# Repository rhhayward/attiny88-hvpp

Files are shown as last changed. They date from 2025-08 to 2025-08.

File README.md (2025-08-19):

### Important

The code has been tested on a breadboard, and the original pcb has been
validated to work.  There were two changes made since ordering: 1. The
attiny88 footprint was not wide enough, so it was widened in REV002.
2. The 12v source had left and right reversed - that is fixed in REV003.

Caveat emptor:  If you order PCBs from this, be prepared for them not
to work.  You have been warned.

### ATTINY88 High Voltage Parallel Programmer

This project came from a bricked attiny88. I was changing the fuses, and after
one particular update, none of the methods to program or update fuses worked.
The programmer was unable even to read the signature or fuses. However, the code
was still working, albeit terribly slowly. An LED which previously blinked once
per second was taking minutes to complete a blink cycle. While ATTINY88
microcontrollers are inexpensive and could easily be replaced, I took it as a
challenge to unbrick this one. Reading the datasheet and online, a high voltage
parallel programmer was what was needed, but I couldn't find code or a
schematic, so I worked to get a hvpp programmer working.

This was validated working with a purple pi (off-brand rp2040), a 12v boost
regulator, and the aforementioned bricked ATTINY88. I was then able to use the
`WRITEFUS` command to unbrick the device.  I implemented a few additional
commands as well.  The entire suite of possible commands is not yet available,
but should be doable leveraging the primitives that are already implemented.

### How to

The wiring is laid out in the .ino file. The only additional circuitry is that
the 5v providing the ATTINY88's VCC and the 12v necessary for the RST pin are
switched using a transistor+mosfet. All other wiring is direct from the purple
pi to the ATTINY88.  You can see the full schematic in
`/kicad/attiny88-hvpp.kicad_sch`
(https://kicanvas.org/?github=https%3A%2F%2Fgithub.com%2Frhhayward%2Fattiny88-hvpp%2Ftree%2Fmain%2Fkicad).

Once wired, you canbuild and push the code to the purple pi. I have tested this
using the Arduino IDE 2 with the Raspberry Pi Pico profile which worked for me
with no trouble. With the code running, connect to the purple pi's USB Serial
port.  The code will always prefix its output with a `*`.  It will emit some
help on start.  Once it announces done, you can start issuing commands.

## Commands

* `READSIG` - read and display signature bytes
* `READCAL` - read and display calibration byte
* `READFUS` - read and display fuse and lock bytes
* `READFLA 0x<START> 0x<END>` - read and display flash from start to end
* `WRITEFUS 0x<low> 0x<high> 0x<extended>` - write low high and extended
  fuses, then read and display fuse and lock bytes

## Example execution

```
* starting up
* setting up pin modes and values
* setting up pin modes and values - DONE
* entering programming mode
* entering programming mode - DONE
* Commands:
* READSIG - read signature and write to stdout
* READCAL - read calibration byte and write to stdout
* READFUS - read fuses and lock bytes
* READFLA 0x<START> 0x<END> - read flash from START to END.  Each must be 4 hex digits.
* WRITEFUS 0x<LOW> 0x<HIGH> 0x<EXTENDED> - write LOW HIGH and EXTENDED fuses.  Each must be 2 hex digits.
* * * ready
```
```
READSIG
```
```
* SIGNATURE: 0x1E,0x93,0x11 IDENT: ATTINY88
```
```
READFUS
```
```
* FUSE l=0x37 h=0xDF x=0xFF LOCK 0xFF
```
```
READCAL
```
```
* calibration byte: 0x9D
```
```
READFLA 0x0000 0x0010
```
```
* start=0x0000 end=0x0010
* 0x0000   13c0 22c0 21c0 20c0 1fc0 1ec0 1dc0 1cc0  1bc0 1ac0 19c0 18c0 17c0 16c0 74c0 14c0
```

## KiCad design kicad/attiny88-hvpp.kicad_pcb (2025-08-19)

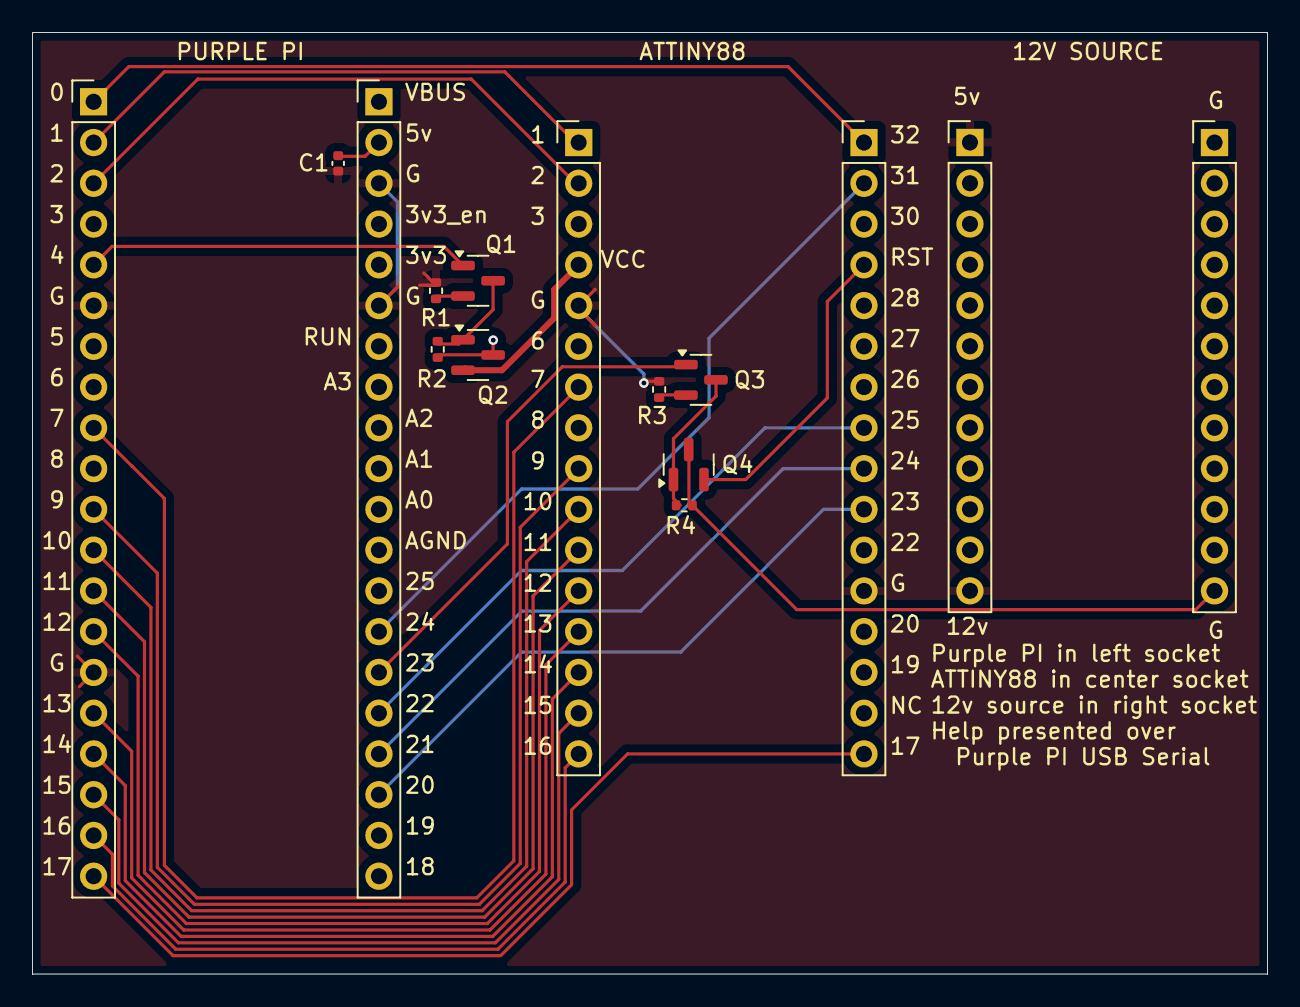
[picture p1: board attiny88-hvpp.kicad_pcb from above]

Board: 2 copper layers, 77.0 x 58.7 mm, 15 parts (0 on the bottom side), 28 nets.

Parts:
C1: 1u; C_0402_1005Metric
J1: 12v_reg_left_neg; PinHeader_1x12_P2.54mm_Vertical
J2: 12v_reg_right_pos; PinHeader_1x12_P2.54mm_Vertical
J3: purle_pi_left; PinHeader_1x20_P2.54mm_Vertical
J4: purle_pi_right; PinHeader_1x20_P2.54mm_Vertical
J5: ATTINY88_LEFT; PinHeader_1x16_P2.54mm_Vertical
J6: ATTINY88_RIGHT; PinHeader_1x16_P2.54mm_Vertical
Q1, Q3: MMBT3904; SOT-23
Q2, Q4: IRLML6402; SOT-23
R1, R3: 2k2; R_0402_1005Metric
R2, R4: 220k; R_0402_1005Metric

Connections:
/5v: C1.1, J2.1, J4.2, Q2.3 (D), R2.2
/12v: J2.12, Q4.3 (D), R4.2
/ATT5v: J5.4, Q2.2 (S)
/BS1: J3.3, J5.2
/BS2: J4.16, J6.8
/CLKI: J3.9, J5.7
/DATA0: J4.17, J6.9
/DATA1: J4.18, J6.10
/DATA2: J3.20, J6.16
/DATA3: J3.19, J5.16
/DATA4: J3.18, J5.15
/DATA5: J3.17, J5.14
/DATA6: J3.16, J5.13
/DATA7: J3.14, J5.12
/PAGEL: J3.13, J5.11
/RDYBSY: J4.14, J6.2
/XA0: J3.11, J5.9
/XA1: J3.12, J5.10
/pi_pin0: J3.1, J6.1
/pi_pin1: J3.2, J5.1
/pi_pin4: J3.5, Q1.1 (B)
/pi_pin23: J4.15, Q3.1 (B)
/~RST: J6.4, Q4.2 (S)
GND: C1.2, J1.1, J1.12, J3.6, J3.15, J4.3, J4.6, J5.5, J6.12, R1.2, R3.2
unnamed: Q1.3 (C), Q2.1 (G), R2.1
unnamed: Q1.2 (E), R1.1
unnamed: Q3.3 (C), Q4.1 (G), R4.1
unnamed: Q3.2 (E), R3.1

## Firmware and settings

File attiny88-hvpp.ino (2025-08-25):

/*
 * attiny88-hvpp.ino
 *
 *  Created on: 6 Aug 2025
 *      Author: Ryan Hayward
 *
 * This program implements  HVPP programming protocol from the ATTINY88
 *   datasheet. The pins defined were tested on a Purple Pi rp2040 and a
 *   12v boost converter. Both the VCC_PIN and RST_PIN connect to the base
 *   of an NPN transistor (BC547), the emitter of which goes to ground
 *   through a 2k2 resistor.  The collector is hooked to the gate of an
 *   P-Channel mosfet (IRLML6402).  They have 5v and 12v directly to their
 *   source as well as through a 220k resistor to the source to hold it
 *   high.  The drain is hooked to the ATTINY88's VCC and RST pins.
 *   Otherwise, all the pins hook directly to the ATTINY88.  The pin
 *   setup was chosen to try and make PCB design simpler.  The only other
 *   component used when testing was a 1u capacitor from 5v to GND to smooth
 *   any noise, but that is likely unnecessary.
 *
 * Usage: Write this to a purple pi, wire it up as discussed above, and
 *   run it with an ATTINY88 connected up.  The program will emit some help to
 *   the Serial output, and take commands to execute.  Those which are
 *   currently supported are:
 *
 *   * READSIG - read and display signature bytes
 *   * READCAL - read and display calibration byte
 *   * READFUS - read and display fuse and lock bytes
 *   * READFLA 0x<START> 0x<END> - read and display flash from START to END
 *   * READROM 0x<START> 0x<END> - read and display EEPROM from START to END
 *   * WRITEFUS 0x<low> 0x<high> 0x<extended> - write low high and extended
 *       fuses, then read and display fuse and lock bytes
 *   * CHIPERASE - perform chip erase - flash and eeprom (depending on EESAVE)
 *   * LOADDATA 0x<START> <DATA> - load DATA into buffer starting at START
 *   * SHOWDATA 0x<START> 0x<END> - read and display buffer from START to END
 *   * WRITEFLA - write data from buffer to flash - will erase chip as CHIPERASE
 *
 * TODO:  These features are not yet implemented:
 *   * write eeprom
*/

#define SERIAL_SPEED 9600
// Purple PI built-in LED Pin
#define LED_PIN 25

// HVPP to ATTINY88 pin setup

// pi.0 <-> attiny88.32
// pi.1 <-> attiny88.1
// pi.2 <-> attiny88.2
// pi.3 <-> attiny88.3
// pi.4 -> transistor -> mosfet -> attiny88.4
// pi.7 <-> attiny88.7
// pi.9 <-> attiny88.9
// pi.10 <-> attiny88.10
// pi.11 <-> attiny88.11
// pi.12 <-> attiny88.12
// pi.13 <-> attiny88.13
// pi.14 <-> attiny88.14
// pi.15 <-> attiny88.15
// pi.16 <-> attiny88.16
// pi.17 <-> attiny88.17
// pi.20 <-> attiny88.23
// pi.21 <-> attiny88.24
// pi.22 <-> attiny88.25
// pi.23 -> transistor -> mosfet -> attiny88.29
// pi.24 <-> attiny88.31

#define OE_PIN 0
#define WR_PIN 1
#define VCC_PIN 4
#define BS1_PIN 2
#define CLKI_PIN 7
#define XA0_PIN 9
#define XA1_PIN 10
#define PAGEL_PIN 11
#define D0_PIN 12
#define D1_PIN 13
#define D2_PIN 14
#define D3_PIN 15
#define D4_PIN 16
#define D5_PIN 17
#define D6_PIN 20
#define D7_PIN 21
#define BS2_PIN 22
#define RST_PIN 23
#define RDYBSY_PIN 24

// mark pin as output, with initial HIGH or LOW
void setOutput(int pin, int initValue) {
  pinMode(pin, OUTPUT);
  digitalWrite(pin, initValue);
}

// setup pins with their initial values
void setStartingPinModesAndValues() {
  // set outputs low initially
  setOutput(LED_PIN, LOW);
  setOutput(VCC_PIN, LOW);
  setOutput(RST_PIN, LOW);
  setOutput(PAGEL_PIN, LOW);
  setOutput(XA1_PIN, LOW);
  setOutput(XA0_PIN, LOW);
  setOutput(BS1_PIN, LOW);
  setOutput(BS2_PIN, LOW);
  setOutput(CLKI_PIN,LOW);
  setOutput(OE_PIN, LOW);
  setOutput(WR_PIN, LOW);

  // RDYBSY is an input
  pinMode(RDYBSY_PIN, INPUT);
}

// follow procedure to initiate programming mode
void enterProgrammingMode() {

  // setting low is redundant at first, but
  //  still, let's do it for completeness

  // PAGEL=0 ; XA1=0 ; XA0=0 ; BS1=0
  digitalWrite(PAGEL_PIN, LOW);
  digitalWrite(XA1_PIN, LOW);
  digitalWrite(XA0_PIN, LOW);
  digitalWrite(BS1_PIN, LOW);

  // make sure everything is off
  digitalWrite(VCC_PIN, LOW);
  digitalWrite(RST_PIN, LOW);

  // Enable VCC to ATT
  digitalWrite(VCC_PIN, HIGH);

  // wait 20 to 60 us
  delayMicroseconds(50);

  // Put 12v on RST
  digitalWrite(RST_PIN, HIGH);
  delayMicroseconds(300);

  // set active low pins high
  digitalWrite(OE_PIN, HIGH);
  digitalWrite(WR_PIN, HIGH);
  blink(1);
}

// blink the LED a number of times
void blink(int times) {
  for(int i=0;i<times;i++) {
    digitalWrite(LED_PIN, HIGH);
    delay(100);
    digitalWrite(LED_PIN, LOW);
    delay(100);
  }
  delay(200);
}

// put data out onto data pins
void writeDataPins(uint8_t data) {
  // set data pins as output
  pinMode(D0_PIN, OUTPUT);
  pinMode(D1_PIN, OUTPUT);
  pinMode(D2_PIN, OUTPUT);
  pinMode(D3_PIN, OUTPUT);
  pinMode(D4_PIN, OUTPUT);
  pinMode(D5_PIN, OUTPUT);
  pinMode(D6_PIN, OUTPUT);
  pinMode(D7_PIN, OUTPUT);

  // split data out into pins
  digitalWrite(D0_PIN, (data >> 0) & 0x01);
  digitalWrite(D1_PIN, (data >> 1) & 0x01);
  digitalWrite(D2_PIN, (data >> 2) & 0x01);
  digitalWrite(D3_PIN, (data >> 3) & 0x01);
  digitalWrite(D4_PIN, (data >> 4) & 0x01);
  digitalWrite(D5_PIN, (data >> 5) & 0x01);
  digitalWrite(D6_PIN, (data >> 6) & 0x01);
  digitalWrite(D7_PIN, (data >> 7) & 0x01);
}

// read data from data pins
uint8_t readDataPins() {
  uint8_t result = 0;

  // Set data pins as inputs
  pinMode(D0_PIN, INPUT);
  pinMode(D1_PIN, INPUT);
  pinMode(D2_PIN, INPUT);
  pinMode(D3_PIN, INPUT);
  pinMode(D4_PIN, INPUT);
  pinMode(D5_PIN, INPUT);
  pinMode(D6_PIN, INPUT);
  pinMode(D7_PIN, INPUT);

  // Read each pin and shift it to the correct bit position
  result |= (digitalRead(D0_PIN) & 0x01) << 0;
  result |= (digitalRead(D1_PIN) & 0x01) << 1;
  result |= (digitalRead(D2_PIN) & 0x01) << 2;
  result |= (digitalRead(D3_PIN) & 0x01) << 3;
  result |= (digitalRead(D4_PIN) & 0x01) << 4;
  result |= (digitalRead(D5_PIN) & 0x01) << 5;
  result |= (digitalRead(D6_PIN) & 0x01) << 6;
  result |= (digitalRead(D7_PIN) & 0x01) << 7;

  return result;
}

// CLKI low for 1us, high for 1us
void pulseClockPin() {
  digitalWrite(CLKI_PIN, HIGH);
  delayMicroseconds(1);
  digitalWrite(CLKI_PIN, LOW);
  delayMicroseconds(1);
}

// follow procedure to load a command
void loadCommand(uint8_t data) {
  // XA1=1 ; XA0=0
  digitalWrite(XA1_PIN, HIGH);
  digitalWrite(XA0_PIN, LOW);

  // BS1=0
  digitalWrite(BS1_PIN, LOW);

  // load data
  writeDataPins(data);

  // pulse the clock
  pulseClockPin();
}

// follow procedure to load the address low byte
void loadAddressLowByte(uint8_t data) {
  // XA1=0 ; XA0=0
  digitalWrite(XA1_PIN, LOW);
  digitalWrite(XA0_PIN, LOW);

  // BS1=0
  digitalWrite(BS1_PIN, LOW);

  // DATA=data
  writeDataPins(data);

  pulseClockPin();
}

// follow procedure to load the address high byte
void loadAddressHighByte(uint8_t data) {
  // XA1=0 ; XA0=0
  digitalWrite(XA1_PIN, LOW);
  digitalWrite(XA0_PIN, LOW);

  // BS1=1
  digitalWrite(BS1_PIN, HIGH);

  // DATA=data
  writeDataPins(data);

  pulseClockPin();
}

// follow procedure to load the data low byte
void loadDataLowByte(uint8_t data) {
  // XA1=0 ; XA0=1
  digitalWrite(XA1_PIN, LOW);
  digitalWrite(XA0_PIN, HIGH);

  // DATA=data
  writeDataPins(data);

  pulseClockPin();
}


// variables for signature data
uint8_t sig[3] = {0};
String ident = "UNKNOWN";
// follow procedure to read signature
void readSignature() {
  // set "read signature" command
  loadCommand(0b00001000);

  // read three signature bytes
  for(uint8_t loc=0x00;loc<0x03;loc++) {
    // 0x00, 0x01, 0x02
    loadAddressLowByte(loc);

    // 0E=0 ; BS1=-0
    digitalWrite(OE_PIN, LOW);
    digitalWrite(BS1_PIN, LOW);
    // read signature
    sig[loc] = readDataPins();
    // OE=1
    digitalWrite(OE_PIN, HIGH);
  }

  // identify if possible
  if(sig[0] == 0x1e && sig[1] == 0x93 && sig[2] == 0x11) {
    ident = "ATTINY88";
  } else {
    ident = "UNKNOWN";
  }
}

// variables to hold fuses
uint8_t lfuse = 0;
uint8_t hfuse = 0;
uint8_t efuse = 0;
uint8_t lock = 0;
// follow procedure to read fuse and lock bits
void readFuseAndLockBits() {
  // set "read fuse and lock" command
  loadCommand(0b00000100);

  // OE=0 ; BS1=0 ; BS2=0
  digitalWrite(OE_PIN, LOW);
  digitalWrite(BS1_PIN, LOW);
  digitalWrite(BS2_PIN, LOW);
  // read the low fuse
  lfuse = readDataPins();

  // OE=0 ; BS1=1 ; BS2=1
  digitalWrite(OE_PIN, LOW);
  digitalWrite(BS1_PIN, HIGH);
  digitalWrite(BS2_PIN, HIGH);
  // read the high fuse
  hfuse = readDataPins();

  // OE=0 ; BS1=0 ; BS2=1
  digitalWrite(OE_PIN, LOW);
  digitalWrite(BS1_PIN, LOW);
  digitalWrite(BS2_PIN, HIGH);
  // read the extended fuse
  efuse = readDataPins();

  // OE=0 ; BS1=1 ; BS2=0
  digitalWrite(OE_PIN, LOW);
  digitalWrite(BS1_PIN, HIGH);
  digitalWrite(BS2_PIN, LOW);
  // read the lock bits
  lock = readDataPins();

  // OE=1
  digitalWrite(OE_PIN, HIGH);
}

// variable to hold calibration byte
uint8_t calibration_byte = 0;
// follow procedure to read calibration byte
void readCalibrationByte() {
  // load the "read calibration byte" command
  loadCommand(0b00001000);
  // set address low byte to 0x00
  loadAddressLowByte(0x00);
  // OE=0 ; BS1=1
  digitalWrite(OE_PIN, LOW);
  digitalWrite(BS1_PIN, HIGH);
  // read the calibration byte
  calibration_byte = readDataPins();
  // OE=1
  digitalWrite(OE_PIN, HIGH);
}

void chipErase() {
  // XA1=1 ; XA0=0 ; BS1=0
  digitalWrite(XA1_PIN, HIGH);
  digitalWrite(XA0_PIN, LOW);
  digitalWrite(BS1_PIN, LOW);

  // load command for chip erase
  loadCommand(0b10000000);

  // pulse cliki to load the command
  pulseClockPin();

  // pulse write pin low
  pulseWritePin();

  // wait for ready busy to go high
  do { delay(100); } while(readReadyBusy() == 0);


}

// read location from flash
uint16_t readFlash(uint16_t loc) {
  // break 16 bit loc into high and low bytes
  uint8_t low = loc & 0x00ff;
  uint8_t high = (loc & 0xff00) >> 8;
  // load the command to read flash
  loadCommand(0b00000010);

  // load high and low bytes of address
  loadAddressHighByte(high);
  loadAddressLowByte(low);

  // BS1=0 triggers low byte read
  digitalWrite(BS1_PIN, LOW);
  // OE=0 to start read
  digitalWrite(OE_PIN, LOW);
  // read the low data
  uint16_t value = readDataPins() << 8;
  // OE=1 to clear read
  digitalWrite(OE_PIN, HIGH);

  // BS1=1 triggers high byte read
  digitalWrite(BS1_PIN, HIGH);
  // OE=0 to start read
  digitalWrite(OE_PIN, LOW);
  // or in the high data
  value |= readDataPins();
  // OE=1 to clear read
  digitalWrite(OE_PIN, HIGH);

  return value;
}

// read location from flash
uint8_t readEeprom(uint16_t loc) {
  // break 16 bit loc into high and low bytes
  uint8_t low = loc & 0x00ff;
  uint8_t high = (loc & 0xff00) >> 8;
  // load the command to read eeprom
  loadCommand(0b00000011);

  // load high and low bytes of address
  loadAddressHighByte(high);
  loadAddressLowByte(low);

  // OE=0 ; BS1=0 makes byte available on DATA
  digitalWrite(OE_PIN, LOW);
  digitalWrite(BS1_PIN, LOW);
  uint8_t value = readDataPins();

  // OE=1 to clear read
  digitalWrite(OE_PIN, HIGH);

  return value;
}

// read the RDYBSY pin - single value
uint8_t readReadyBusy() {
  uint8_t readyBusy = digitalRead(RDYBSY_PIN);
  return readyBusy;
}

// write low fuse value
void writeLowFuse(uint8_t fuse_val) {
  // load the "write fuse" command
  loadCommand(0b01000000);

  // load the value into the data low byte
  loadDataLowByte(fuse_val);

  // pulse WR low
  pulseWritePin();

  // wait for RDYBSY to go HIGH
  do { delay(100); } while(readReadyBusy() == 0);
}

void pulseWritePin() {
  digitalWrite(WR_PIN, LOW);
  delayMicroseconds(20);
  digitalWrite(WR_PIN, HIGH);
}

// write high fuse value
void writeHighFuse(uint8_t fuse_val) {
  // load the write fuse command
  loadCommand(0b01000000);

  // load the value into the data low byte
  loadDataLowByte(fuse_val);

  // set BS1=1, BS2=0
  digitalWrite(BS1_PIN, HIGH);
  digitalWrite(BS2_PIN, LOW);

  // pulse WR low
  pulseWritePin();

  // wait for RDYBSY to go HIGH
  do { delay(100); } while(readReadyBusy() == 0);

  // reset BS1
  digitalWrite(BS1_PIN, LOW);
}

// write extended fuse value
void writeExtendedFuse(uint8_t fuse_val) {
  // load the write fuse command
  loadCommand(0b01000000);

  // load the value into the data low byte
  loadDataLowByte(fuse_val);

  // set BS1=0, BS2=1u
  digitalWrite(BS1_PIN, LOW);
  digitalWrite(BS2_PIN, HIGH);

  // pulse WR low
  pulseWritePin();

  // wait for RDYBSY to go HIGH
  do { delay(100); } while(readReadyBusy() == 0);

  // reset BS2
  digitalWrite(BS2_PIN, LOW);
}

void writeFlash(int len, uint16_t *bytes) {

  // Before writing flash, we must do a chip erase
  chipErase();

  // A) Load Command "Write Flash"
  // XA1=1 ; XA0=0 ; BS1=0 ; load command 0b00010000 ; pulse clock
  digitalWrite(XA1_PIN, HIGH);
  digitalWrite(XA0_PIN, LOW);
  digitalWrite(BS1_PIN, LOW);
  loadCommand(0b00010000);
  pulseClockPin();

  for(uint8_t i=0;i<=len/32;i++) {
    uint8_t addr_high_byte = 0;
    for(int pos=i*32;pos<len && pos<i*32+32;pos++) {

      // extract data and address
      uint8_t data_low_byte = (bytes[pos] & 0xff00) >> 8;
      uint8_t data_high_byte = bytes[pos] & 0x00ff;

      uint8_t addr_low_byte = pos & 0x00ff;
      addr_high_byte = (pos & 0xff00) >> 8;

      Serial.printf(" * writing byte pos=%d, addr=%02X%02X, data=%02X%02X\n",
          pos,
          addr_high_byte, addr_low_byte,
          data_high_byte, data_low_byte);

      // B) Load Address Low Byte
      // XA1=0 ; XA0=0 ; BS1=0 ; DATA = addr_low_byte ; pulse clock
      digitalWrite(XA1_PIN, LOW);
      digitalWrite(XA0_PIN, LOW);
      digitalWrite(BS1_PIN, LOW);
      writeDataPins(addr_low_byte);
      pulseClockPin();

      // C) Load Data Low Byte
      // XA1=0 ; XA0=1 ; DATA = data_low_byte ; pulse clock
      digitalWrite(XA1_PIN, LOW);
      digitalWrite(XA0_PIN, HIGH);
      writeDataPins(data_low_byte);
      pulseClockPin();

      // D) Load Data High Byte
      // BS1=1 ; XA1=0 ; XA0=1 ; DATA = data_high_byte ; pulse clock
      digitalWrite(BS1_PIN, HIGH);
      digitalWrite(XA1_PIN, LOW);
      digitalWrite(XA0_PIN, HIGH);
      writeDataPins(data_high_byte);
      pulseClockPin();

      // E) Latch Data
      // BS1=1 ; pulse PAGEL high
      digitalWrite(BS1_PIN, HIGH);
      digitalWrite(PAGEL_PIN, HIGH);
      delayMicroseconds(1);
      digitalWrite(PAGEL_PIN, LOW);
      delayMicroseconds(1);
    } // F) Repeat for a page or until done

    // G) Load Address High Byte
    // XA1=0 ; XA0=0 ; BS1=1 ; DATA = addr_high_byte ; pulse clock
    digitalWrite(XA1_PIN, LOW);
    digitalWrite(XA0_PIN, LOW);
    digitalWrite(BS1_PIN, HIGH);
    writeDataPins(addr_high_byte);
    pulseClockPin();

    // H) Program Page
    // pulse WR low ; wait for RDYBSY to go HIGH
    Serial.printf(" * clocking in page\n");
    pulseWritePin();
    do { delay(100); } while(readReadyBusy() == 0);
  } // I) Repeat until done

  // J) End Page Programming
  // XA1=1 ; XA0=0 ; load command 0b00000000 ; pulse clock
  Serial.printf(" * NOP to complete programming\n");
  digitalWrite(XA1_PIN, HIGH);
  digitalWrite(XA0_PIN, LOW);
  loadCommand(0b00000000);
  pulseClockPin();
}

// extract from String s a hex value from start for len characters -
//   returns a long, can be cast to smaller lengths
long getHexVal(String s, uint8_t start, uint8_t len) {
  // String to substr into
  String hex;
  // char array so that we can use strtoul
  char hexChars[len+1];


  hex = s.substring(start, start+len);
  hex.toCharArray(hexChars, len+1);
  return strtoul(hexChars, NULL, 16); // 16 defines hex
}

// in setup we do the following:
//   * Start Serial
//   * Setup pins
//   * Enter Programming Mode
//   * Write some help text
void setup() {

  Serial.begin(SERIAL_SPEED);

  delay(3000);
  Serial.println("* starting up");
  Serial.println("* setting up pin modes and values");
  setStartingPinModesAndValues();
  Serial.println("* setting up pin modes and values - DONE");
  blink(1);

  Serial.println("* entering programming mode");
  enterProgrammingMode();
  Serial.println("* entering programming mode - DONE");
  blink(2);

  // blink(3);
  Serial.println("* Commands:");
  Serial.println("* READSIG - read signature and write to stdout");
  Serial.println("* READCAL - read calibration byte and write to stdout");
  Serial.println("* READFUS - read fuses and lock bytes");

  Serial.println("* READFLA 0x<START> 0x<END> - read flash from START to END.  Each must be 4 hex digits.");
  Serial.println("* READROM 0x<START> 0x<END> - read EEPROM from START to END.  Each must be 4 hex digits.");
  Serial.println("* WRITEFUS 0x<LOW> 0x<HIGH> 0x<EXTENDED> - write LOW HIGH and EXTENDED fuses.  Each must be 2 hex digits.");

  Serial.println("* CHIPERASE - Perform Chip Erase, clearing flash and EEPROM (depending on EESAVE fuse).");
  Serial.println("* LOADDATA 0x<START> <DATA> - load DATA into buffer starting at START.");
  Serial.println("* SHOWDATA 0x<START> 0x<END> - read and display buffer from START to END");
  Serial.println("* WRITEFLA - write data from buffer to flash - will erase chip as CHIPERASE");

  Serial.println("* * * ready");
}
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
void loop() {

  // get user input
  cmd = Serial.readStringUntil('\n');
  cmd.trim();

  // find if we got a command
  if(cmd.equalsIgnoreCase("READSIG")) {
    // read and display signature bytes
    readSignature();
    Serial.printf("* SIGNATURE: 0x%02X,0x%02X,0x%02X IDENT: %s \n", sig[0], sig[1], sig[2], ident.c_str());
  } else if(cmd.equalsIgnoreCase("READCAL")) {
    // read and display calibration byte
    readCalibrationByte();
    Serial.printf("* CALIBRATION BYTE: 0x%02X\n", calibration_byte);
  } else if(cmd.equalsIgnoreCase("READFUS")) {
    // read and display fuse and lock bits
    readFuseAndLockBits();
    Serial.printf("* FUSE l=0x%02X h=0x%02X x=0x%02X LOCK 0x%02X\n", lfuse, hfuse, efuse, lock);
  } else if(cmd.startsWith("READFLA 0x") && cmd.length() == 21) {
    // read and display flash bytes - notice special handling of customer provided
    //   arguments - read from start to end
    uint16_t start = (uint16_t)getHexVal(cmd, 10, 4);
    uint16_t end = (uint16_t)getHexVal(cmd, 17, 4);

    Serial.printf("* START=0x%04x END=0x%04x\n", start, end);
    for(uint16_t i=0;i<(end-start);i++) {
      uint16_t byte = readFlash(start+i);
      // print address every 16 bytes
      if((i%16)==0) Serial.printf("* 0x%04x  ", (start+i));
      // print each byte
      Serial.printf(" %04x", byte);
      // print an extra space half way through
      if((i%16)==7) Serial.printf(" ");
      // print a newline every last of 16 bytes
      if((i%16)==15) Serial.printf("\n");
    }
    Serial.println(); // may write an extra line - that's okay by me
  } else if(cmd.startsWith("WRITEFLA") && cmd.length() == 8) {
    Serial.printf("* WRITING FLASH\n");

    // write bytes to flash
    writeFlash(num_bytes, bytes);

    Serial.printf("* DONE WRITING FLASH\n");
  } else if(cmd.startsWith("SHOWDATA 0x") && cmd.length() ==22 ) {
    // read and display stored flash bytes - notice special handling of customer provided
    //   arguments - read from start to end
    uint16_t start = (uint16_t)getHexVal(cmd, 11, 4);
    uint16_t end = (uint16_t)getHexVal(cmd, 18, 4);

    Serial.printf("* START=0x%04x END=0x%04x NUMBYTES=%d\n", start, end, num_bytes);
    for(uint16_t i=start;i<end;i++) {
      // print address every 16 bytes
      if((i%16)==0) Serial.printf("* 0x%04x  ", i);
      // print each byte
      Serial.printf(" %04x", bytes[i]);
      // print an extra space half way through
      if((i%16)==7) Serial.printf(" ");
      // print a newline every last of 16 bytes
      if((i%16)==15) Serial.printf("\n");
    }
    Serial.println(); // may write an extra line - that's okay by me
  } else if(cmd.startsWith("LOADDATA 0x") && cmd.length() > 11) {
    Serial.printf("* LOADING DATA\n");
    uint16_t offset = (uint16_t)getHexVal(cmd, 11, 4);

    // extract bytes from cmd
    for(int i=0;i<(cmd.length()-16)/4;i++) {
      int pos = i*4+16;
      bytes[i+offset] = (uint16_t)getHexVal(cmd, pos, 4);
      if(num_bytes < (i+offset+1)) num_bytes = (i+offset+1);
      Serial.printf("* bytes[%d]=0x%04x\n", i+offset, bytes[i+offset]);
    }

    Serial.printf("* DONE LOADING DATA\n");
  } else if(cmd.startsWith("WRITEFUS 0x") && cmd.length() == 23) {
    // write fuse bytes, then read and display fuse and lock bits to show what happenedu
    uint8_t l = (uint8_t)getHexVal(cmd, 11, 2);
    uint8_t h = (uint8_t)getHexVal(cmd, 16, 2);
    uint8_t x = (uint8_t)getHexVal(cmd, 21, 2);

    Serial.printf("* WRITING FUSES l=0x%02X h=0x%02X x=0x%02X\n", l, h, x);
    writeLowFuse(l);
    writeHighFuse(h);
    writeExtendedFuse(x);
    Serial.printf("* DONE WRITING FUSES.  READING FUSES...\n");
    readFuseAndLockBits();
    Serial.printf("* FUSE l=0x%02X h=0x%02X x=0x%02X LOCK 0x%02X\n", lfuse, hfuse, efuse, lock);
  } else if(cmd.startsWith("READROM 0x") && cmd.length() == 21) {
    // read and display eeprom bytes - notice special handling of customer provided
    //   arguments - read from start to end
    uint16_t start = (uint16_t)getHexVal(cmd, 10, 4);
    uint16_t end = (uint16_t)getHexVal(cmd, 17, 4);

    Serial.printf("* start=0x%04x end=0x%04x\n", start, end);
    for(uint16_t i=0;i<(end-start);i++) {
      uint8_t byte = readEeprom(start+i);
      // print address every 16 bytes
      if((i%16)==0) Serial.printf("* 0x%04x  ", (start+i));
      // print each byte
      Serial.printf(" %02x", byte);
      // print an extra space half way through
      if((i%16)==7) Serial.printf(" ");
      // print a newline every last of 16 bytes
      if((i%16)==15) Serial.printf("\n");
    }
    Serial.println(); // may write an extra line - that's okay by me
  } else if(cmd.startsWith("CHIPERASE") && cmd.length() == 9) {
    Serial.printf("* PERFORMING CHIP ERASE\n");
    chipErase();
    Serial.printf("* DONE PERFORMING CHIP ERASE\n");

  }
}

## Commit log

2025-08-07 schematic and pcb (untested)
    [attiny88-hvpp.kicad_pcb, attiny88-hvpp.kicad_sch]
2025-08-07 capitalizing calibration byte output to match other output
2025-08-19 had left and right 12v switched
    [attiny88-hvpp.kicad_pcb]
